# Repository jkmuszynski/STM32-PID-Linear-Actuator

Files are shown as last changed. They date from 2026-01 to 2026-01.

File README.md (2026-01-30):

# Projekt Regulatora PID - Pozycjonowanie Liniowe (STM32)





Projekt zrealizowany w ramach laboratorium "Systemy Mikroprocesorowe". Jest to kompletny system sterowania pozycją wózka liniowego w pętli zamkniętej (Closed-Loop Control) z wykorzystaniem regulatora PID.

System składa się z dwóch części:
1.  **Firmware (STM32):** Odpowiedzialny za sterowanie silnikiem w czasie rzeczywistym.
2.  **Software (PC):** Aplikacja Dashboard do wizualizacji danych i strojenia regulatora.

## 🚀 Funkcjonalności

* **Regulator PID:** Implementacja z członem proporcjonalnym, całkującym (z Anti-Windup) i różniczkującym.
* **Enkoder Absolutny:** Obsługa enkodera magnetycznego AS5600 po magistrali I2C.
* **Auto-Homing:** Automatyczne bazowanie wózka po starcie systemu (dojazd do krańcówki).
* **Bezpieczeństwo:**
    * **Hardware Limits:** Obsługa krańcówek fizycznych (blokada ruchu w stronę przeszkody).
    * **Soft Limits:** Programowe ograniczenie zakresu ruchu (0-255mm).
    * **Stall Detection:** Wykrywanie zablokowania silnika i awaryjne wyłączenie.
* **Tryb Hybrydowy:** Możliwość sterowania z poziomu aplikacji PC lub manualnie za pomocą enkodera obrotowego (gałki).
* **Telemetria Real-Time:** Wysyłanie danych (pozycja, uchyb, PWM) do PC z częstotliwością 10Hz.

## 🛠️ Sprzęt (Hardware)

* **Mikrokontroler:** STM32 Nucleo (F411RE).
* **Czujnik Pozycji:** AS5600 (Magnes neodymowy diametralny).
* **Napęd:** Silnik DC +Śruba.
* **Sterownik Silnika:** Mostek H (BTS7960).
* **Interfejs:** Enkoder obrotowy (KY-040) z przyciskiem.

## 💻 Oprogramowanie

### 1. Firmware (STM32)
Kod napisany w **STM32CubeIDE** przy użyciu bibliotek HAL.
* **TIM10:** Główna pętla sterowania (Przerwanie co 2ms).
* **TIM4:** Generacja PWM dla silnika.
* **I2C1:** Komunikacja z czujnikiem AS5600.
* **UART2 (DMA):** Komunikacja z komputerem.

### 2. Dashboard (Python)
Aplikacja napisana w Pythonie przy użyciu biblioteki `tkinter` oraz `matplotlib`.
* Rysowanie wykresów w czasie rzeczywistym (Pozycja, Uchyb, PWM).
* Eliminacja opóźnień (Anti-Lag buffering).
* Dynamiczne skalowanie wykresów.

## ⚙️ Instalacja i Uruchomienie

### Wymagania
* STM32CubeIDE (do edycji kodu C).
* Python 3.x.

### Uruchomienie Aplikacji PC
1.  Zainstaluj wymagane biblioteki:
    ```bash
    pip install pyserial matplotlib
    ```
2.  Podłącz STM32 do USB.
3.  Uruchom skrypt:
    ```bash
    python pid_tuner.py
    ```

## 📡 Protokół Komunikacyjny (UART)

Baudrate: `115200`

**Komendy PC -> STM32:**
* `SET:200` - Ustaw pozycję zadaną na 200mm (Tryb Auto).
* `MAN` - Przełącz w tryb manualny (Sterowanie gałką).
* `PID:1.5:0.01:0.5` - Zmień nastawy (Kp, Ki, Kd).

**Dane STM32 -> PC (Format CSV):**
`DAT, czas, cel, pozycja, uchyb, pwm, kp, kd, tryb`

## 👥 Autorzy

* **Jakub Muszyński**
* **Kacper Nele**

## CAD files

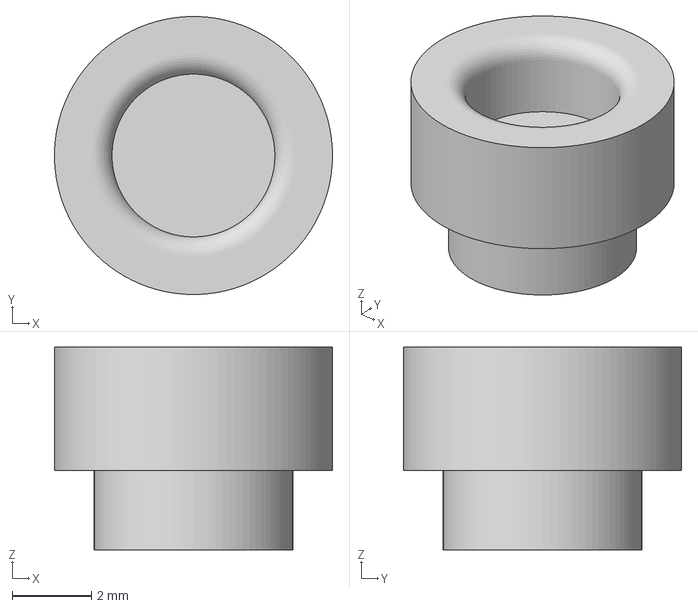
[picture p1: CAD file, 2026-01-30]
3D models/mocowanie_magnesu_projekt_SM.3mf
7.00 x 7.00 x 5.10 mm

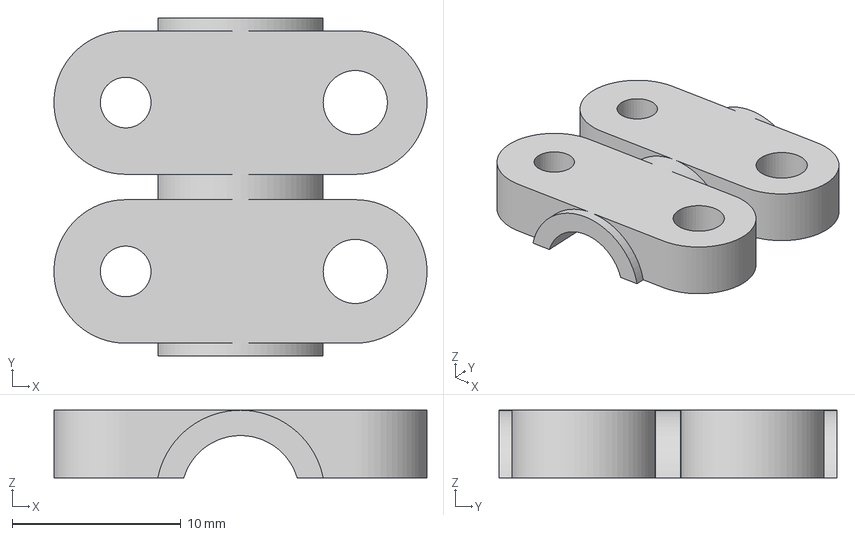
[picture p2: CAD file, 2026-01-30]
3D models/mocowanie_walu_silnika_ze_sruba_przesuwna_projekt_SM.3mf
22.1 x 20.0 x 4.00 mm

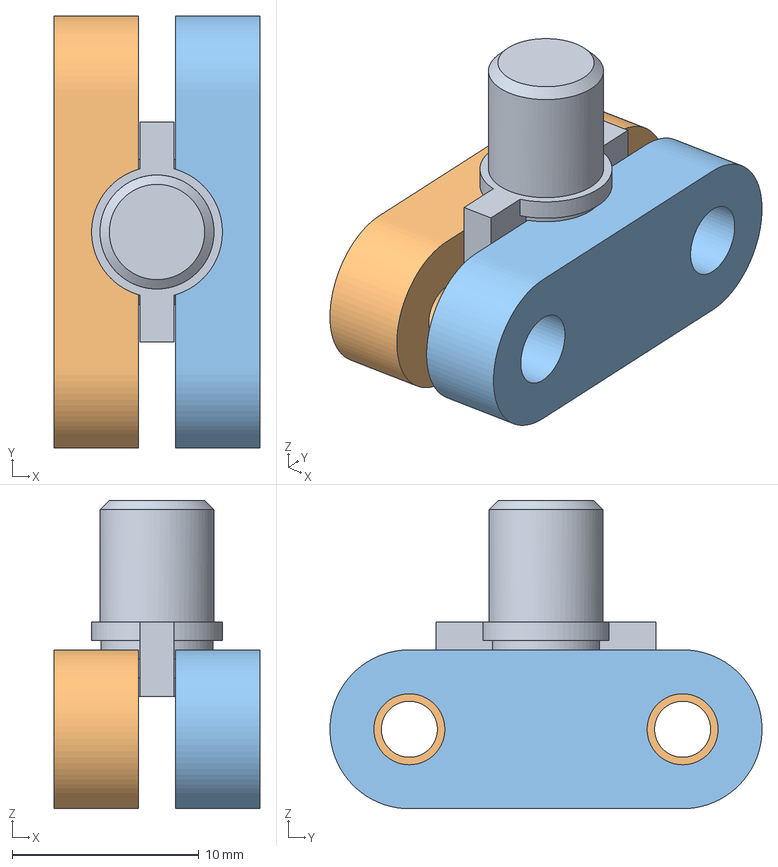
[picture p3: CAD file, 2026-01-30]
3D models/mocowanie_gwintu_do_lozyska_projekt_SM.3mf
11.0 x 23.1 x 16.5 mm
Bryła1
Bryła2
Bryła3

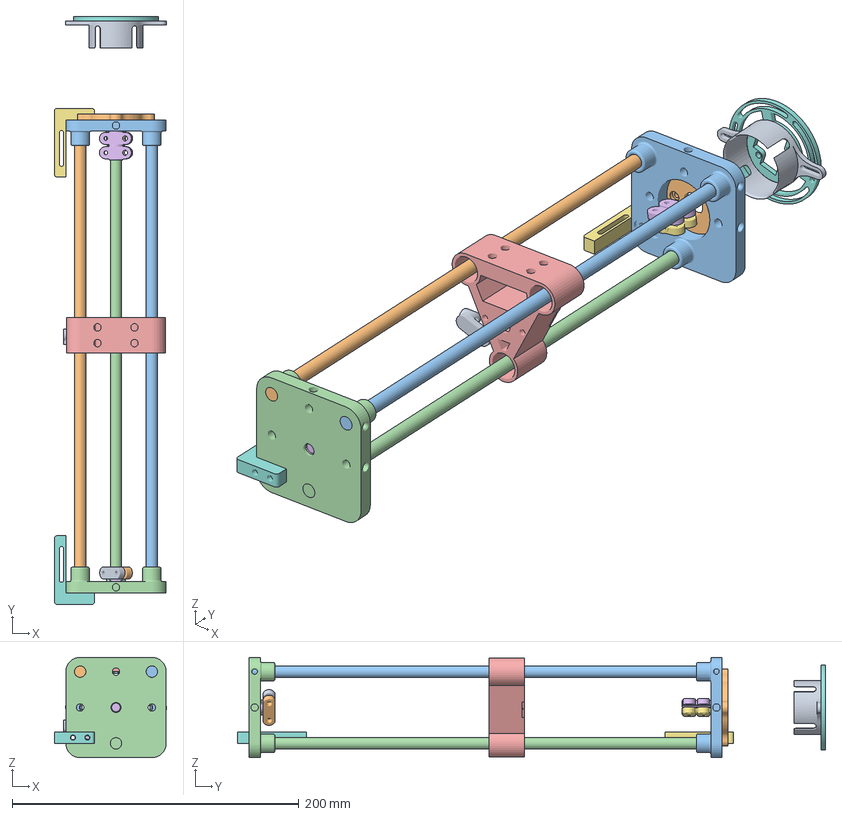
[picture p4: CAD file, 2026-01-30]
3D models/zlozenie_suwnicy_liniowej_projekt_SM.3mf
78.3 x 410.0 x 70.0 mm
Bryła1 x 16
Bryła2
Bryła3

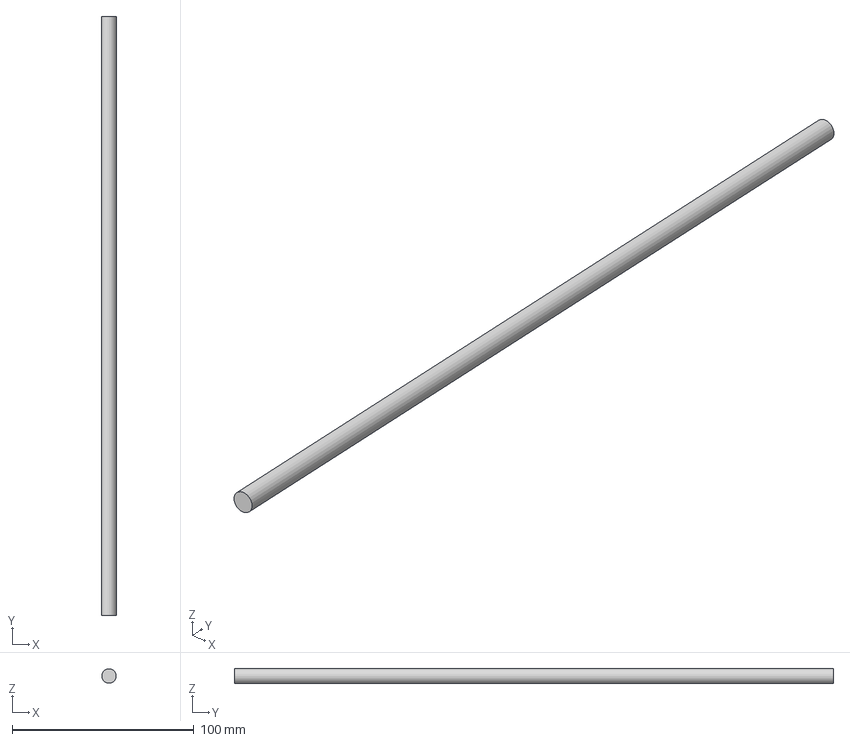
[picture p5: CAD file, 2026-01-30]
3D models/suwnica_liniowa_projekt_SM.3mf
8.00 x 330.0 x 8.00 mm

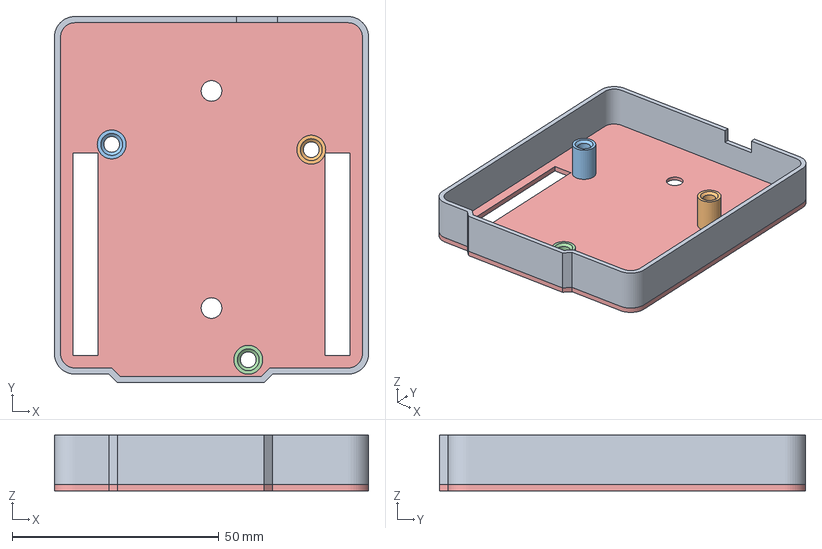
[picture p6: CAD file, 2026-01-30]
3D models/PłytkaF411RE_pod_obodowe.3mf
76.0 x 88.5 x 13.5 mm
Bryła1
Bryła10
Bryła11
Bryła12
Bryła9

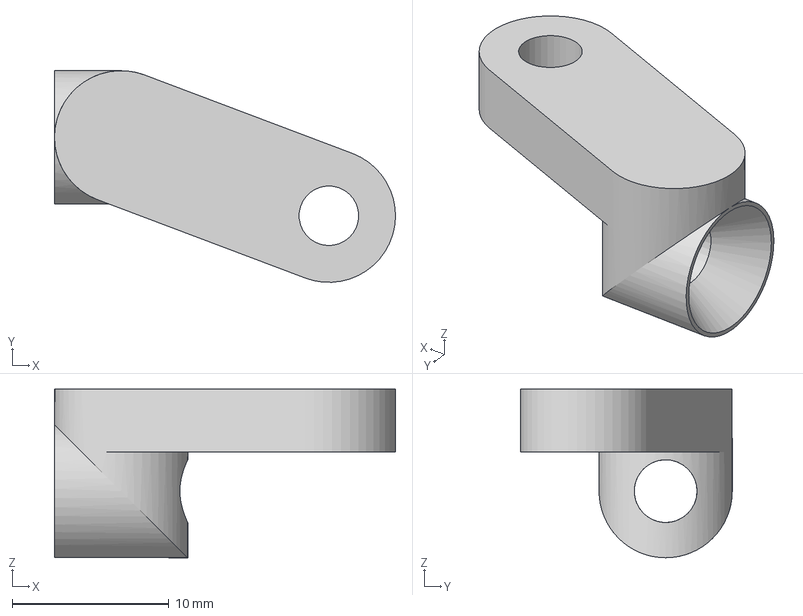
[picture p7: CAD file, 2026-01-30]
3D models/mocowanie_metalu_pomiarowego_projekt_SM.3mf
21.7 x 13.5 x 10.8 mm

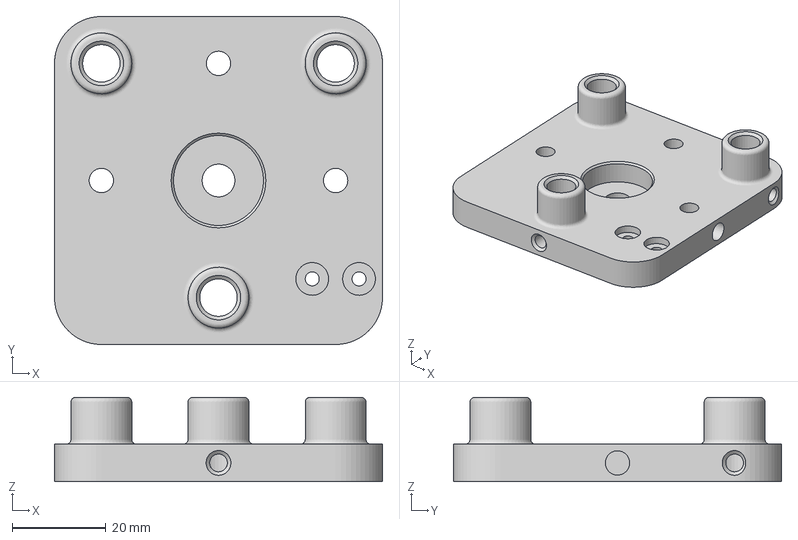
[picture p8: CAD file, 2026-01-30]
3D models/tylnia_plansza_suwnicy_str_silnik_projekt_SM.3mf
70.0 x 70.0 x 18.0 mm

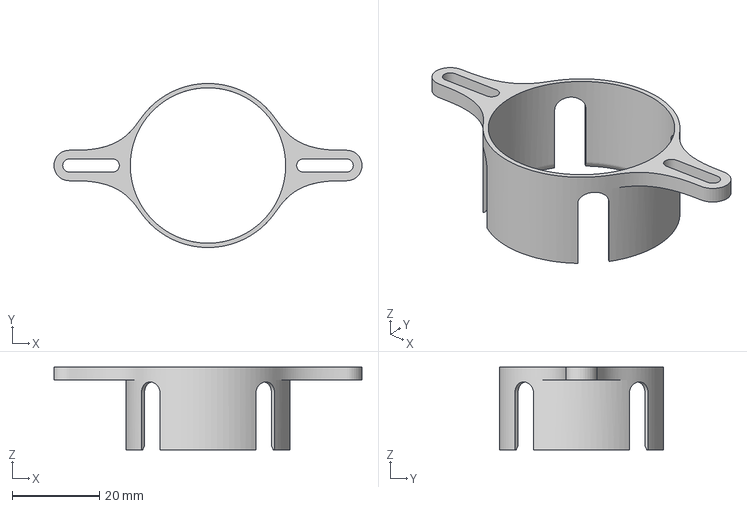
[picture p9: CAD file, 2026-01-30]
3D models/Regulowane_mocowanie_enkodera_do_silnika_wersja_2.3mf
70.6 x 37.6 x 19.0 mm

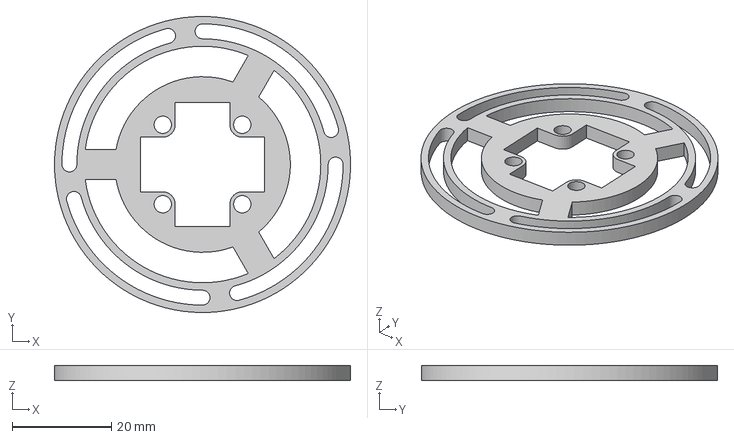
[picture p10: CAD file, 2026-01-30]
3D models/mocowanie_czujnika_wersja_2_projekt_SM.3mf
59.6 x 59.6 x 3.00 mm

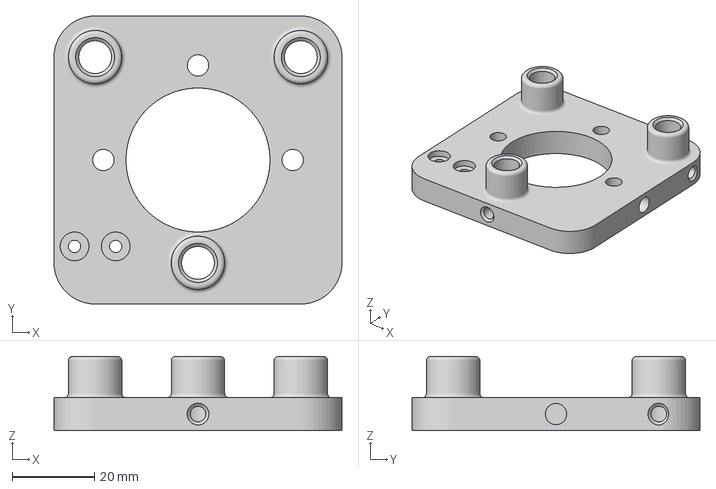
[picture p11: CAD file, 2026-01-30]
3D models/przednia_plansza_suwnicy_str_silnik_projekt_SM.3mf
70.0 x 70.0 x 18.0 mm

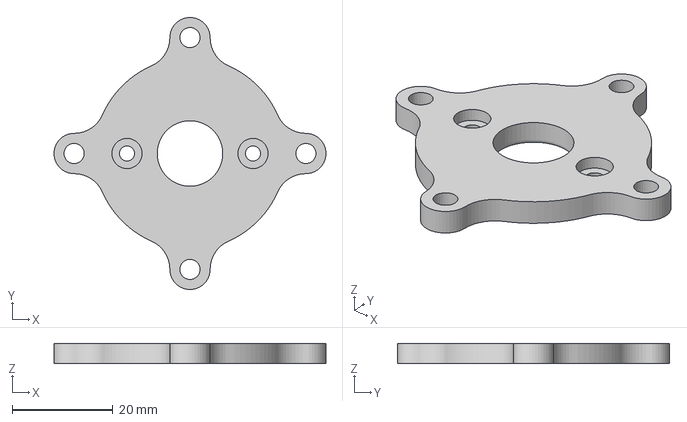
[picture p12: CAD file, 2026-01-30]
3D models/mocowanie_silnika_do_obudowy_projekt_SM.3mf
54.0 x 54.0 x 4.00 mm

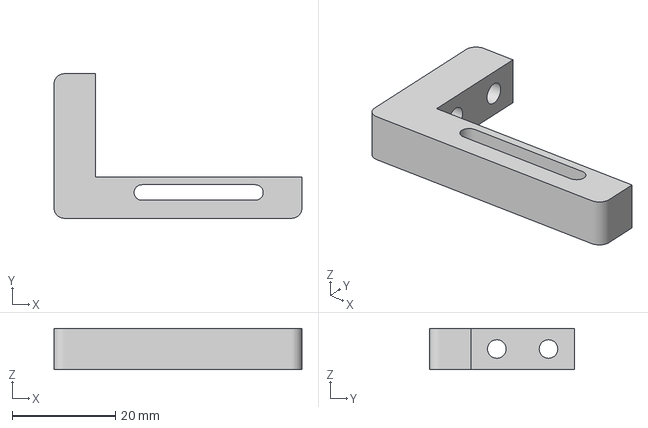
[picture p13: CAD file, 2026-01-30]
3D models/mocowanie_czujnika_projekt_SM.3mf
48.0 x 28.0 x 8.00 mm

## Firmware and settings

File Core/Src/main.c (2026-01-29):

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
/* Includes ------------------------------------------------------------------*/
#include "main.h"
/* USER CODE BEGIN Includes */
#include <stdio.h>
#include <string.h>
#include <stdlib.h>
//#include "lcd_i2c.h"
/* USER CODE END Includes */
I2C_HandleTypeDef hi2c1;
TIM_HandleTypeDef htim2;
TIM_HandleTypeDef htim4;
TIM_HandleTypeDef htim10;
UART_HandleTypeDef huart2;
DMA_HandleTypeDef hdma_usart2_tx;

/* USER CODE BEGIN PV */

#define MIN_PWM 0
#define MAX_PWM 275 // Maksimum bo powyżej zasilacz/sterownik odcina
#define AS5600_ADDR (0x36 << 1)
#define RAW_ANGLE_REG 0x0C
#define IMPULSES_PER_MM   3296    // Ile impulsów enkodera na 1mm
#define MOTOR_DEADZONE    20      // Poniżej tego PWM silnik buczy a nie jedzie
#define HOMING_SPEED      -200    // Prędkość bazowania
#define HOMING_TIMEOUT_MS 10000   // 10 sekund na znalezienie bazy (inaczej BŁĄD)
#define MAX_TRAVEL_MM     255     // Maksymalny wysuw
#define PID_INTERVAL_MS   2       // Co ile działa PID (zgodnie z ustawieniami Timer10)
#define PID_DEADBAND 400

// --- ZMIENNE SYSTEMOWE ---

volatile int32_t total_position = 0;
volatile int32_t active_target_imp = 0;
volatile int motor_pwm = 0;
volatile uint16_t last_angle = 0;
volatile int is_first_read = 1;
int16_t knob_val = 0;
int32_t preview_position_mm = 0;
uint32_t last_button_time = 0;
char msg[128];
uint32_t uart_timer = 0;

// --- ZMIENNE PID ---
float Kp = 0.05;  // Wzmocnienie proporcjonalne
float Ki = 0.05;  // Całka
float Kd = 0.02; // Różniczka

int32_t error = 0;
int32_t last_error = 0;
int32_t integral = 0;

// Zmienne do komunikacji z PC
uint8_t rx_byte;
uint8_t rx_buffer[32];
uint8_t rx_index = 0;
volatile uint8_t cmd_received_flag = 0;
volatile uint8_t control_mode = 0;// Flaga sterowania: 0 = Gałka (Manual), 1 = PC (Automat)


/* USER CODE END PV */

void SystemClock_Config(void);
static void MX_GPIO_Init(void);
static void MX_DMA_Init(void);
static void MX_USART2_UART_Init(void);
static void MX_I2C1_Init(void);
static void MX_TIM2_Init(void);
static void MX_TIM4_Init(void);
static void MX_TIM10_Init(void);
/* USER CODE BEGIN 0 */

// Funkcje pomocnicze

// Nastawienie prędkości
void Set_Motor_Speed(int speed) {
    if (abs(speed) < MOTOR_DEADZONE) {
        __HAL_TIM_SET_COMPARE(&htim4, TIM_CHANNEL_3, 0);
        __HAL_TIM_SET_COMPARE(&htim4, TIM_CHANNEL_4, 0);
        return;
    }

    int abs_speed = abs(speed);
    if (abs_speed < MIN_PWM) abs_speed = MIN_PWM;
    if (abs_speed > MAX_PWM) abs_speed = MAX_PWM;

    if (speed > 0) {
        __HAL_TIM_SET_COMPARE(&htim4, TIM_CHANNEL_3, abs_speed);
        __HAL_TIM_SET_COMPARE(&htim4, TIM_CHANNEL_4, 0);
    } else {
        __HAL_TIM_SET_COMPARE(&htim4, TIM_CHANNEL_3, 0);
        __HAL_TIM_SET_COMPARE(&htim4, TIM_CHANNEL_4, abs_speed);
    }
}


// Odczyt z enkodera magnetycznego
uint16_t AS5600_ReadAngle(void) {
    uint8_t raw_data[2];
    // Timeout 2ms - musi być krótki, bo jesteśmy w przerwaniu!
    if (HAL_I2C_Mem_Read(&hi2c1, AS5600_ADDR, RAW_ANGLE_REG, I2C_MEMADD_SIZE_8BIT, raw_data, 2, 2) == HAL_OK) {
        return ((raw_data[0] << 8) | raw_data[1]);
    }
    return last_angle;
}


// Update pozycji
void Update_Position() {
    uint16_t curr_angle = AS5600_ReadAngle();
    if (is_first_read) {
        last_angle = curr_angle;
        is_first_read = 0; return;
    }
    int32_t diff = curr_angle - last_angle;
    if (diff > 2048)       total_position -= (4096 - diff);
    else if (diff < -2048) total_position += (4096 + diff);
    else                   total_position += diff;
    last_angle = curr_angle;
}


// Regulator
int Calculate_PID(int32_t current_pos, int32_t target_pos) {
    // 1. Error
    error = current_pos - target_pos;

    if (abs(error) < PID_DEADBAND) {
            error = 0;
            last_error = 0;
            integral = 0;
            return 0;
        }

    // 2. Proportional
    float P = error * Kp;

    // 3. Integral (z Anti-Windup)
    integral += error;
    //if (integral > 2000) integral = 2000;
    //if (integral < -2000) integral = -2000;
    float I = integral * Ki;

    // 4. Derivative
    float D = (error - last_error) * Kd;
    last_error = error;


    int output = (int)(P + I + D);
    if (output > MAX_PWM) output = MAX_PWM;
    if (output < -MAX_PWM) output = -MAX_PWM;

    return output;
}

//  bazowanie z timeoutem
void Auto_Homing(void) {
    char info[] = "BAZOWANIE...\r\n";
    HAL_UART_Transmit(&huart2, (uint8_t*)info, strlen(info), 100);

    Set_Motor_Speed(HOMING_SPEED);

    uint32_t start_tick = HAL_GetTick();


    while (HAL_GPIO_ReadPin(GPIOA, GPIO_PIN_10) != GPIO_PIN_RESET) {
        if (HAL_GetTick() - start_tick > HOMING_TIMEOUT_MS) {
            Set_Motor_Speed(0);
            char err[] = "BLAD: TIMEOUT KRANCOWKI!\r\n";
            HAL_UART_Transmit(&huart2, (uint8_t*)err, strlen(err), 100);
            while(1);
        }
    }

    Set_Motor_Speed(0);
    HAL_Delay(500);
    // Reset systemu
    __disable_irq(); // Wyłączamy przerwania na moment zerowania
    total_position = 0;
    active_target_imp = 0;
    last_angle = AS5600_ReadAngle();
    is_first_read = 0;
    __enable_irq();
    __HAL_TIM_SET_COUNTER(&htim2, 0);
    char ok[] = "BAZOWANIE OK. START.\r\n";
    HAL_UART_Transmit(&huart2, (uint8_t*)ok, strlen(ok), 100);
}

/* USER CODE END 0 */

/**
  * @brief  The application entry point.
  * @retval int
  */
int main(void)
{

  /* MCU Configuration--------------------------------------------------------*/

  /* Reset of all peripherals, Initializes the Flash interface and the Systick. */
  HAL_Init();

  /* Configure the system clock */
  SystemClock_Config();

  /* Initialize all configured peripherals */
  MX_GPIO_Init();
  MX_DMA_Init();
  MX_USART2_UART_Init();
  MX_I2C1_Init();
  MX_TIM2_Init();
  MX_TIM4_Init();
  MX_TIM10_Init();
  /* USER CODE BEGIN 2 */
  HAL_GPIO_WritePin(GPIOB, GPIO_PIN_5, GPIO_PIN_SET);
  HAL_GPIO_WritePin(GPIOB, GPIO_PIN_4, GPIO_PIN_SET);
  HAL_TIM_PWM_Start(&htim4, TIM_CHANNEL_3);
  HAL_TIM_PWM_Start(&htim4, TIM_CHANNEL_4);
  HAL_TIM_Encoder_Start(&htim2, TIM_CHANNEL_ALL);

  // Bazowanie
  Auto_Homing();
  HAL_TIM_Base_Start_IT(&htim10);
  HAL_UART_Receive_IT(&huart2, &rx_byte, 1);
  /* USER CODE END 2 */
  /* Infinite loop */
  /* USER CODE BEGIN WHILE */
  while (1)
  {
    /* USER CODE END WHILE */

    /* USER CODE BEGIN 3 */
	  // --- 1. ODBIÓR KOMEND Z PC --
	  if (cmd_received_flag) {
		  cmd_received_flag = 0;
		  // A. Komenda "MAN" -> Tryb Ręczny (Gałka)
		  if (strncmp((char*)rx_buffer, "MAN", 3) == 0) {
			  control_mode = 0;
			  // Synchronizacja gałki z aktualną pozycją (żeby nie szarpnęło)
			  if (preview_position_mm < 0) preview_position_mm = 0;
			  __HAL_TIM_SET_COUNTER(&htim2, preview_position_mm);
	            }
		  // B. Komenda "SET:xxx" -> Tryb PC
		  else if (strncmp((char*)rx_buffer, "SET:", 4) == 0) {
			  control_mode = 1; // Przełącz na PC
			  int new_mm = atoi((char*)rx_buffer + 4);
			  active_target_imp = new_mm * -IMPULSES_PER_MM;
			  preview_position_mm = new_mm;
		  }
		  else if (strncmp((char*)rx_buffer, "PID:", 4) == 0) {
			  float p, i, d;
			  if (sscanf((char*)rx_buffer, "PID:%f:%f:%f", &p, &i, &d) == 3) {
				  Kp = p; Ki = i; Kd = d;
			  }
		  }
	  }
	  // --- 2. OBSŁUGA MANUALNA (GAŁKA) ---
	  // Działa tylko w trybie 0.
	  if (control_mode == 0) {
		  int16_t raw_knob = (int16_t)__HAL_TIM_GET_COUNTER(&htim2);
		  if (raw_knob < 0) { __HAL_TIM_SET_COUNTER(&htim2, 0); raw_knob = 0; }
		  if (raw_knob > MAX_TRAVEL_MM) { __HAL_TIM_SET_COUNTER(&htim2, MAX_TRAVEL_MM); raw_knob = MAX_TRAVEL_MM; }
		  preview_position_mm = raw_knob;
		  // Przycisk fizyczny
		  if (HAL_GPIO_ReadPin(KNOB_SW_GPIO_Port, KNOB_SW_Pin) == GPIO_PIN_RESET) {
			  if (HAL_GetTick() - last_button_time > 300) {
				  last_button_time = HAL_GetTick();
				  active_target_imp = preview_position_mm * -IMPULSES_PER_MM;
				  HAL_GPIO_TogglePin(LD2_GPIO_Port, LD2_Pin);
			  }
		  }
	  }
	  // --- 3. WYSYŁANIE DANYCH (TELEMETRIA) ---
	  if (HAL_GetTick() - uart_timer >= 100) {
		  uart_timer = HAL_GetTick();
		  if (huart2.gState == HAL_UART_STATE_READY) {
			  int current_mm = total_position / -IMPULSES_PER_MM;
			  int active_mm = active_target_imp / -IMPULSES_PER_MM;
			  int err_mm = error / -IMPULSES_PER_MM;
			  // Format: DAT,czas,CEL,AKTUALNA,ERR,PWM,KP,KD,TRYB
			  int len = sprintf(msg, "DAT,%ld,%d,%d,%d,%d,%d,%d,%d\r\n",HAL_GetTick(),active_mm,current_mm,err_mm,motor_pwm,(int)(Kp*100), (int)(Kd*100), control_mode);
			  HAL_UART_Transmit_DMA(&huart2, (uint8_t*)msg, len);
		  }
	  }
  }
  /* USER CODE END 3 */
}

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
/* USER CODE BEGIN 4 */

void HAL_TIM_PeriodElapsedCallback(TIM_HandleTypeDef *htim) {
    if (htim->Instance == TIM10) {
    	Update_Position();
        motor_pwm = Calculate_PID(total_position, active_target_imp);
        if (HAL_GPIO_ReadPin(GPIOA, GPIO_PIN_10) == GPIO_PIN_RESET && motor_pwm < 0) motor_pwm = 0;
        if (HAL_GPIO_ReadPin(GPIOB, GPIO_PIN_10) == GPIO_PIN_RESET && motor_pwm > 0) motor_pwm = 0;
        Set_Motor_Speed(motor_pwm);
    }
}



// Callback od odbioru UART
void HAL_UART_RxCpltCallback(UART_HandleTypeDef *huart) {
	if (huart->Instance == USART2) {
		if (rx_byte == '\n' || rx_byte == '\r') {
			rx_buffer[rx_index] = 0;
            cmd_received_flag = 1;
            rx_index = 0;
		}
		else {
			if (rx_index < 31) rx_buffer[rx_index++] = rx_byte;
		}
		HAL_UART_Receive_IT(&huart2, &rx_byte, 1);
	}
}




/* USER CODE END 4 */
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


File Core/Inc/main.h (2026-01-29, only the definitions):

#define USART_TX_Pin GPIO_PIN_2
#define USART_TX_GPIO_Port GPIOA
#define USART_RX_Pin GPIO_PIN_3
#define USART_RX_GPIO_Port GPIOA
#define KNOB_SW_Pin GPIO_PIN_4
#define KNOB_SW_GPIO_Port GPIOA
#define LD2_Pin GPIO_PIN_5
#define LD2_GPIO_Port GPIOA
#define SENSOR_R_Pin GPIO_PIN_10
#define SENSOR_R_GPIO_Port GPIOB
#define SENSOR_L_Pin GPIO_PIN_10
#define SENSOR_L_GPIO_Port GPIOA
#define TMS_Pin GPIO_PIN_13
#define TMS_GPIO_Port GPIOA
#define TCK_Pin GPIO_PIN_14
#define TCK_GPIO_Port GPIOA
#define SWO_Pin GPIO_PIN_3
#define SWO_GPIO_Port GPIOB
#define R_EN_Pin GPIO_PIN_4
#define R_EN_GPIO_Port GPIOB
#define L_EN_Pin GPIO_PIN_5
#define L_EN_GPIO_Port GPIOB

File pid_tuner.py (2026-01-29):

import tkinter as tk
from tkinter import ttk
import serial
import serial.tools.list_ports
import matplotlib.pyplot as plt
from matplotlib.backends.backend_tkagg import FigureCanvasTkAgg
from matplotlib.animation import FuncAnimation
import threading
import collections
import time
from typing import Optional

# --- CONFIGURATION ---
BAUDRATE = 115200
HISTORY_LEN = 200
SERIAL_READ_INTERVAL = 0.005
PLOT_UPDATE_INTERVAL = 100
ERROR_THRESHOLD = 2  # mm
MIN_ERROR_SCALE = 5  # mm

# --- APPLICATION CLASS ---
class STM32PIDController:
    def __init__(self, root: tk.Tk):
        self.root = root
        self.root.title("STM32 PID - Autoskaling")
        self.root.geometry("1000x800")
        
        # Serial communication
        self.serial_port: Optional[serial.Serial] = None
        self.is_running = False
        self.pending_target = 0
        self.read_thread: Optional[threading.Thread] = None
        
        # Data buffers
        self.data_target = collections.deque([0] * HISTORY_LEN, maxlen=HISTORY_LEN)
        self.data_actual = collections.deque([0] * HISTORY_LEN, maxlen=HISTORY_LEN)
        self.data_error = collections.deque([0] * HISTORY_LEN, maxlen=HISTORY_LEN)
        self.data_pwm = collections.deque([0] * HISTORY_LEN, maxlen=HISTORY_LEN)
        
        self._setup_ui()
        self._setup_plots()
        
    def _setup_ui(self):
        """Initialize all UI components"""
        # Top frame - Connection controls
        top_frame = tk.Frame(self.root, pady=10, bg="#DDD")
        top_frame.pack(side=tk.TOP, fill=tk.X)
        
        self.port_combobox = ttk.Combobox(top_frame, values=self._get_ports(), width=10)
        self.port_combobox.pack(side=tk.LEFT, padx=5)
        
        self.connect_btn = tk.Button(top_frame, text="Połącz", command=self.connect_serial)
        self.connect_btn.pack(side=tk.LEFT)
        
        self.disconnect_btn = tk.Button(top_frame, text="Rozłącz", 
                                       command=self.disconnect_serial, state="disabled")
        self.disconnect_btn.pack(side=tk.LEFT)
        
        self.status_label = tk.Label(top_frame, text="---", bg="#DDD", width=15)
        self.status_label.pack(side=tk.LEFT)
        
        # Readout frame
        readout = tk.Frame(top_frame, bg="#DDD")
        readout.pack(side=tk.RIGHT, padx=20)
        
        self.lbl_act_target = tk.Label(readout, text="Cel: 0", font=("Arial", 10))
        self.lbl_act_target.pack(side=tk.LEFT, padx=10)
        
        tk.Label(readout, text="UCHYB:").pack(side=tk.LEFT)
        self.lbl_error_val = tk.Label(readout, text="0", font=("Arial", 14, "bold"))
        self.lbl_error_val.pack(side=tk.LEFT)
        
        self.lbl_mode_val = tk.Label(readout, text="---", font=("Arial", 10, "bold"))
        self.lbl_mode_val.pack(side=tk.LEFT, padx=10)
        
        # Bottom frame - Controls
        btm = tk.Frame(self.root, pady=10)
        btm.pack(side=tk.BOTTOM, fill=tk.X)
        
        # PID controls
        pid_frame = tk.LabelFrame(btm, text="PID")
        pid_frame.pack(side=tk.LEFT, padx=10, fill=tk.Y)
        
        tk.Label(pid_frame, text="P:").pack(side=tk.LEFT)
        self.entry_kp = tk.Entry(pid_frame, width=5)
        self.entry_kp.insert(0, "1.7")
        self.entry_kp.pack(side=tk.LEFT)
        
        tk.Label(pid_frame, text="I:").pack(side=tk.LEFT)
        self.entry_ki = tk.Entry(pid_frame, width=5)
        self.entry_ki.insert(0, "0.0")
        self.entry_ki.pack(side=tk.LEFT)
        
        tk.Label(pid_frame, text="D:").pack(side=tk.LEFT)
        self.entry_kd = tk.Entry(pid_frame, width=5)
        self.entry_kd.insert(0, "0.0")
        self.entry_kd.pack(side=tk.LEFT)
        
        tk.Button(pid_frame, text="Send", command=self.send_pid, bg="orange").pack(side=tk.LEFT, padx=5)
        
        # Control frame
        control_frame = tk.LabelFrame(btm, text="Sterowanie")
        control_frame.pack(side=tk.LEFT, padx=10, fill=tk.BOTH, expand=True)
        
        tk.Button(control_frame, text="TRYB MANUAL (Gałka)", 
                 command=self.send_manual, bg="lightblue").pack(fill=tk.X)
        
        scale_frame = tk.Frame(control_frame)
        scale_frame.pack(fill=tk.X, pady=5)
        
        self.scale = tk.Scale(scale_frame, from_=0, to=255, orient=tk.HORIZONTAL, 
                             command=self._on_slider_move)
        self.scale.pack(side=tk.LEFT, fill=tk.X, expand=True)
        
        self.lbl_pending = tk.Label(control_frame, text="Przesuń suwak...", fg="gray")
        self.lbl_pending.pack()
        
        tk.Button(control_frame, text="ZATWIERDŹ CEL [ENTER]", 
                 command=self.send_confirm_target, bg="#90EE90", 
                 font=("Arial", 10, "bold")).pack(fill=tk.X, pady=2)
    
    def _setup_plots(self):
        """Initialize matplotlib plots"""
        self.fig, (self.ax1, self.ax2, self.ax3) = plt.subplots(3, 1, figsize=(8, 6), sharex=True)
        self.fig.subplots_adjust(hspace=0.2)
        
        # Position plot
        self.line_target, = self.ax1.plot([], [], 'g--', label='Cel', linewidth=1.5)
        self.line_actual, = self.ax1.plot([], [], 'b', label='Pozycja', linewidth=1.5)
        self.ax1.set_ylabel("Poz [mm]")
        self.ax1.legend(loc="upper right")
        self.ax1.grid(True, alpha=0.3)
        self.ax1.set_ylim(-10, 265)
        self.ax1.set_xlim(0, HISTORY_LEN)
        
        # Error plot
        self.line_error, = self.ax2.plot([], [], 'orange', label='Uchyb', linewidth=1.5)
        self.ax2.set_ylabel("Err [mm]")
        self.ax2.grid(True, alpha=0.3)
        self.ax2.axhline(y=0, color='k', linestyle='-', alpha=0.3, linewidth=0.8)
        
        # PWM plot
        self.line_pwm, = self.ax3.plot([], [], 'r', label='PWM', linewidth=1.5)
        self.ax3.set_ylabel("PWM")
        self.ax3.grid(True, alpha=0.3)
        self.ax3.set_ylim(-1100, 1100)
        self.ax3.axhline(y=0, color='k', linestyle='-', alpha=0.3, linewidth=0.8)
        
        self.canvas = FigureCanvasTkAgg(self.fig, master=self.root)
        self.canvas.get_tk_widget().pack(fill=tk.BOTH, expand=True)
        
        # Start animation
        self.ani = FuncAnimation(self.fig, self._update_plot, 
                                interval=PLOT_UPDATE_INTERVAL, 
                                blit=False, cache_frame_data=False)
    
    # --- SERIAL COMMUNICATION ---
    def _get_ports(self) -> list:
        """Get list of available serial ports"""
        return [port.device for port in serial.tools.list_ports.comports()]
    
    def connect_serial(self):
        """Connect to selected serial port"""
        port = self.port_combobox.get()
        if not port:
            self.status_label.config(text="Wybierz port", fg="red")
            return
            
        try:
            self.serial_port = serial.Serial(port, BAUDRATE, timeout=0.01)
            self.serial_port.reset_input_buffer()
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

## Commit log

2026-01-29 Add PID controller firmware and Python tuning app
    This commit uploads the complete source code for the linear actuator project.
    Changes included:
    - Added STM32 firmware source code (Core, Drivers) with PID logic, AS5600 encoder support, and safety limits.
    - Added 'pid_tuner.py' - a Python script for real-time data visualization and tuning via UART.
    - Configured project settings (.ioc, .cproject).
    - Cleaned up repository by removing unnecessary build artifacts (Debug/Release folders).
2026-01-29 Add README for PID Regulator project
    Added detailed project documentation for PID Regulator and Linear Positioning system using STM32.
2026-01-30 3D models
    [PłytkaF411RE_pod_obodowe.3mf, Regulowane_mocowanie_enkodera_do_silnika_wersja_2.3mf, mocowanie_czujnika_projekt_SM.3mf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]

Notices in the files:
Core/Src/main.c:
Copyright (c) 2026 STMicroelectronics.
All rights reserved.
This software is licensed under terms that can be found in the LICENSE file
